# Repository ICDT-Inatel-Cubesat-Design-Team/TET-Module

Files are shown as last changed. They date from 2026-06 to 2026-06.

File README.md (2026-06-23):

<div align="center">
  ICDT Logo
</div>
<h1 align="center">TET Module</h1>

<p align="center">
    
    
    
    
    
</p>

<p align="center">
    <a href="#overview">Overview</a> •
    <a href="#repository-organization">Repository Organization</a> •
    <a href="#releases">Releases</a> •
    <a href="#references">References</a> •
    <a href="#license">License</a>
</p>

## Overview
This project involves the development of the **TET (Telemetry, Encoding & Transmission)** module tailored for a 1U CubeSat platform. The system is engineered to handle TT&C (Tracking, Telemetry, and Command) capabilities, providing long-range telemetry and low-power wireless communication based on the Semtech LR1121 RF transceiver architecture and an STM32L431 microcontroller.

<p align="center">
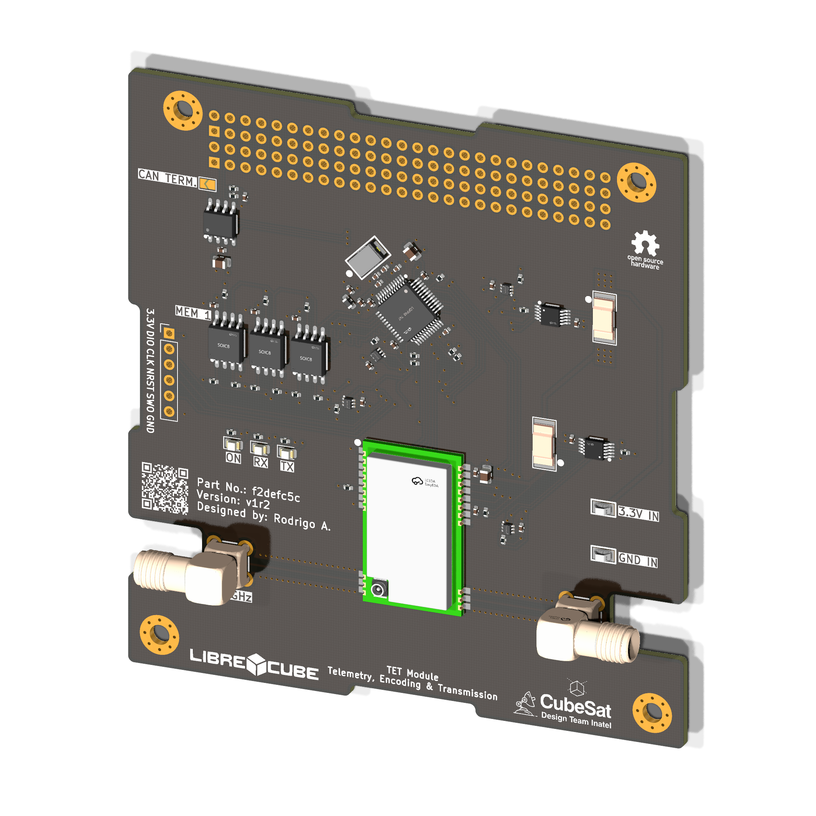
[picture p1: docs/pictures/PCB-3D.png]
    
</p>

**Technical Parameters**
- **RF Architecture:** E80-900M2213S (LR1121)
- **Supported Bands:** Dual-band operation (915 MHz and 2.4 GHz)
- **Modulation Schemes:** LoRa, GFSK, FLRC, and LR-FHSS.
- **RF Interfaces:** Dedicated SMA/IPEX outputs for external antennas
- **External Interfaces:** SPI, GPIO, and CAN bus (via TCAN3414).
- **Power Input:** 3 independent 5 V input channels from the EPS (via PC/104)
- **Power Regulation:** Independent, regulated low-noise 3.3 V rail.
- **Onboard Sensors:** INA226 (current and voltage monitoring) and TMP112 (temperature monitoring and thermal alerts via I2C).
- **Storage:** 3 external SPI flash memories configured with TMR (Triple Modular Redundancy) for telemetry buffering and data storage.

## Repository Organization

* `docs`: Technical documentation and datasheets.
* `hardware`: Core hardware files.
    * `3D`: 3D models (.step).
    * `Fabrication`: BOM and Gerber files for JLCPCB manufacturing.
    * `PCB`: KiCad schematics and layout design.
* `firmware`: Examples of firmware implementation.

## Releases

<table>
  <thead>
    <tr>
      <th>Render</th>
      <th>Board Name</th>
      <th>Status</th>
      <th>Latest Release</th>
      <th>Date</th>
      <th>Datasheet</th>
      <th>BOM</th>
      <th>Ordering Info</th>
    </tr>
  </thead>
  <tbody>
    <tr>
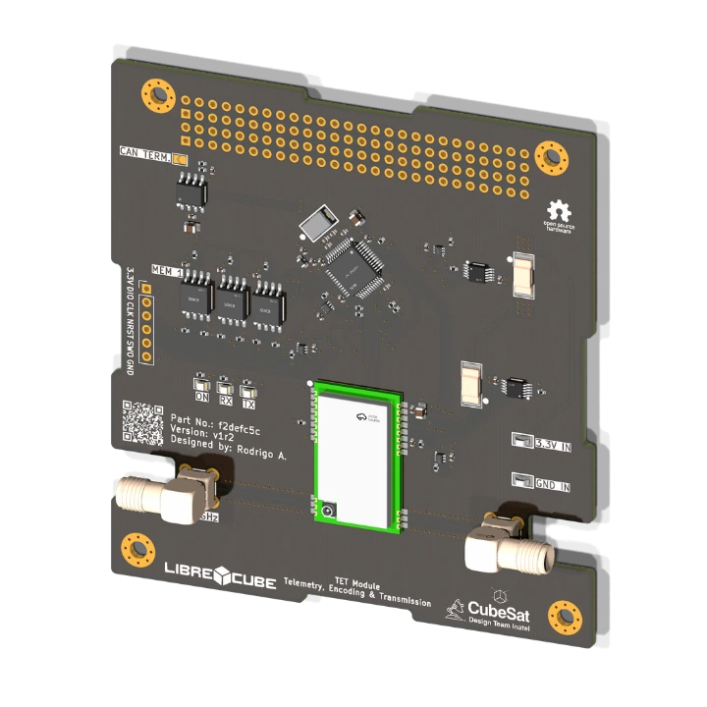
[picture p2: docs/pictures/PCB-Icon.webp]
render
      <td></td>
      <td>TET Module v1</td>
      <td>🧪 Testing</td>
      <td><a href="https://github.com/ICDT-Inatel-Cubesat-Design-Team/TET-Module/releases/tag/v1r2">v1r2</a></td>
      <td>09-06-2026</td>
      <td></td>
      <td>Yes</td>
      <td><a href="hardware/Fabrication/GERBER-TET.zip">GERBER</a> (JLCPCB)</td>
    </tr>
  </tbody>
</table>

## References

This project was inspired by the [TTC](https://github.com/spacelab-ufsc/ttc) and [TTC2](https://github.com/spacelab-ufsc/ttc2) modules from [SpaceLab](https://github.com/spacelab-ufsc/spacelab) UFSC, and the [Build a CubeSat](https://buildacubesat.space/) project. Thank you to both for making your work open-source, and a special thanks to the Build a CubeSat community for their support.

**Missions Associated with this Project**

<p>
  
  
  
<p>

## License

This project is licensed under the permissive, weakly-reciprocal **[CERN-OHL-W-2.0](LICENSE)** open-hardware license. You are free to modify and distribute these files, provided downstream hardware design modifications remain under the same terms.

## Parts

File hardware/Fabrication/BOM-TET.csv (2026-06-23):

Comment | Designator | Footprint | LCSC | Quantity
100 | R5 | R_0402_1005Metric | C25076 | 1
100nF | C1,C14,C19,C2,C20,C22,C23,C24,C25,C26,C27,C30,C31,C32,C33,C40,C5 | C_0402_1005Metric | C307331 | 17
10k | R1,R26,R27,R28,R30,R31,R34,R35,R36,R37,R38,R39,R40,R45 | R_0402_1005Metric | C25744 | 14
10nF | C35 | C_0402_1005Metric | C15195 | 1
10uF | C29,C34 | C_0805_2012Metric | C440198 | 2
120R | FB2 | L_0603_1608Metric | C14709 | 1
1uF | C36,C37 | C_0402_1005Metric | C52923 | 2
200 | R2 | R_0402_1005Metric | C25087 | 1
20pF | C38,C39 | C_0402_1005Metric | C1554 | 2
22uF | C21 | C_0805_2012Metric | C45783 | 1
270 | R10 | R_0402_1005Metric | C2909342 | 1
2m | R32,R7 | RES-SMD_L6.3-W3.1-1 | C695817 | 2
4.7 nF | C8 | C_0402_1005Metric | C1538 | 1
4.7k | R29,R33,R41,R42,R43,R44,R6,R8 | R_0402_1005Metric | C25900 | 8
5015 | U1,U2 | TEST-SMD_L2.7-W1.0 | C2906768 | 2
60.4 | R3,R4 | R_0402_1005Metric | C137954 | 2
8 MHz | U8 | CRYSTAL-SMD_L5.0-W3.2 | C115962 | 1
E80-900M2213S | U14 | WIFIM-SMD_22P-L26.0-W16.0-P1.27-TL | C42464134 | 1
INA226AIDGSR | U21,U3 | MSOP-10_L3.0-W3.0-P0.50-LS5.0-BL | C49851 | 2
ON_LED | D6 | LED_0805_2012Metric | C84256 | 1
RX_LED | D5 | LED_0805_2012Metric | C2297 | 1
SMA | U11,U15 | SMA-TH_SMA-KWE_C7498154 | C7498154 | 2
STM32L431CCT6 | U20 | LQFP-48_L7.0-W7.0-P0.50-LS9.0-BL | C486681 | 1
TCAN3414DR | U5 | SOIC-8_L4.9-W3.9-P1.27-LS6.0-BL | C22396693 | 1
TMP112AIDRLR | U17,U19,U4,U6 | SOT-563_L1.6-W1.2-P0.50-LS1.6-BR | C28927 | 4
TX_LED | D4 | LED_0805_2012Metric | C2296 | 1
W25Q128JVSIQTR | U12,U13,U16 | SOIC-8_L5.3-W5.3-P1.27-LS8.0-BL | C97521 | 3

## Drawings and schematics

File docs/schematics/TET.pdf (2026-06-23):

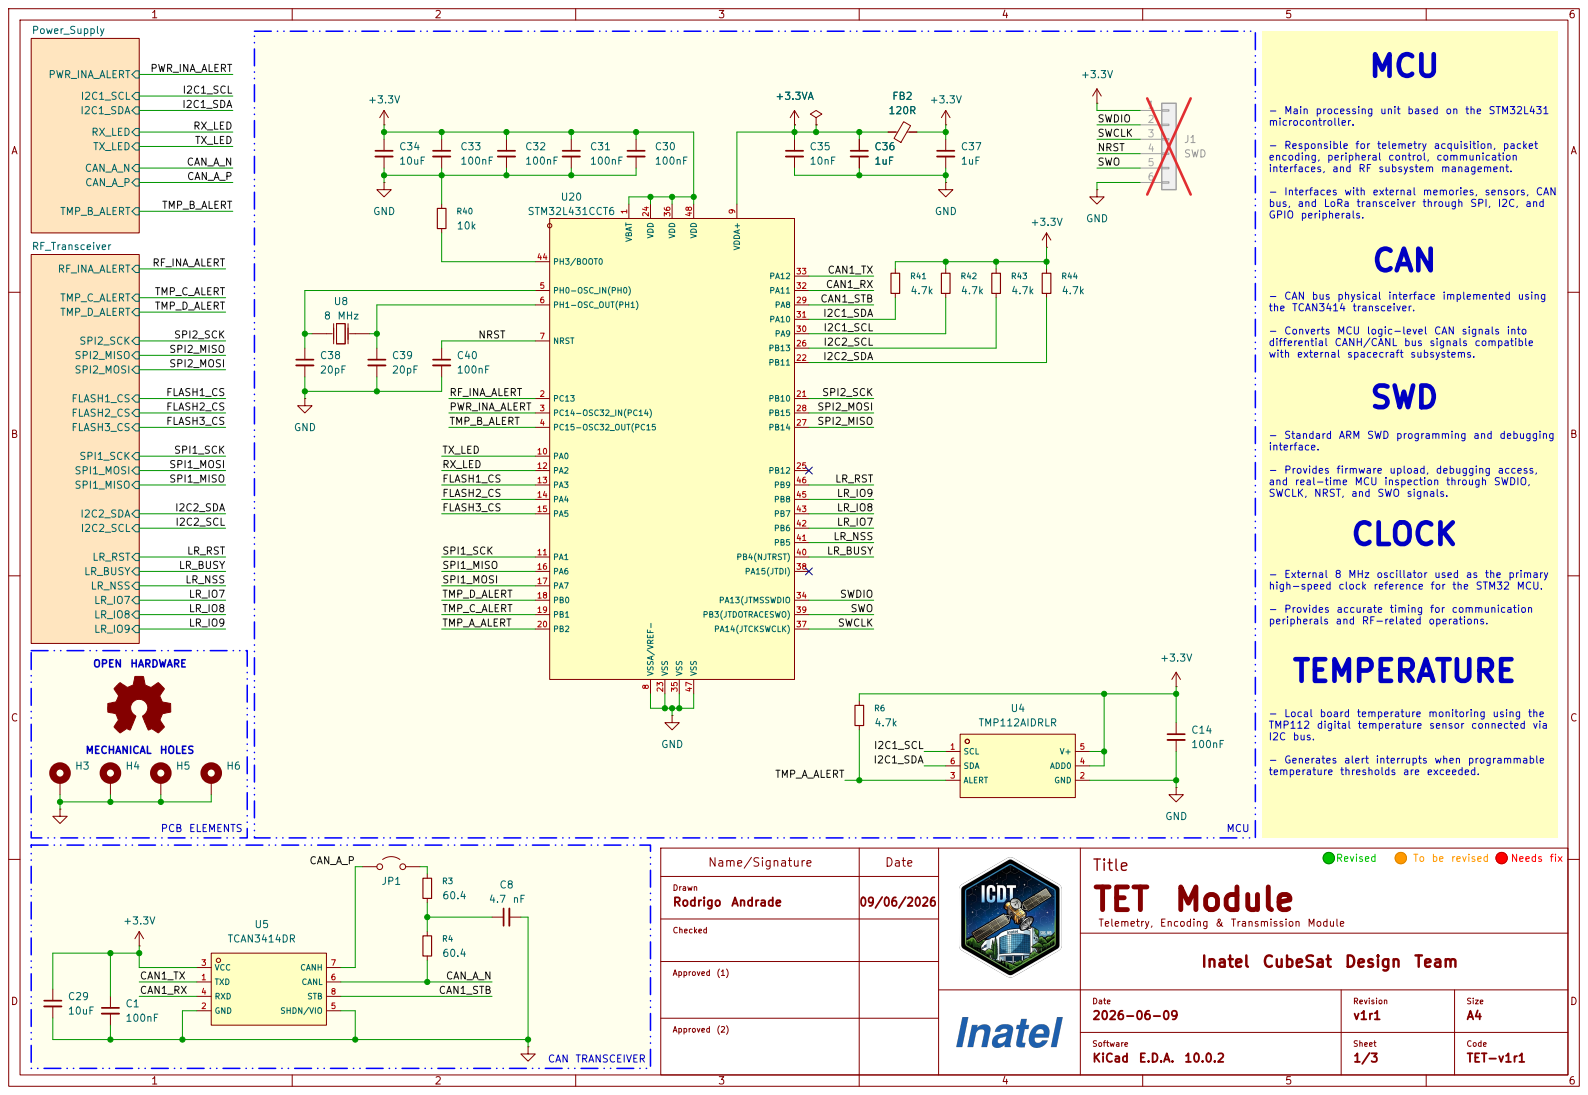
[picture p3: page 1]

- Main processing unit based on the STM32L431 microcontroller. - Responsible for telemetry acquisition, packet

encoding, peripheral control, communication
interfaces, and RF subsystem management. - Interfaces with external memories, sensors, CAN

bus, and LoRa transceiver through SPI, I2C, and GPIO peripherals. - CAN bus physical interface implemented using

9 PA0 10 PA1 11 PA2 12 PA3 13 PA4 14 PA5 15 PA6 16 PA7 17 PB0 18 PB1 19 PB2 20 PB10 21 PB11 22 VSS 23 VDD 24 PB12 25 PB13 26 PB14 27 PB15 28 PA8 29 PA9 30 PA10 31 PA11 32 PA12 33 PA13(JTMSSWDIO 34 VSS 35 VDD 36

the TCAN3414 transceiver. - Converts MCU logic-level CAN signals into

differential CANH/CANL bus signals compatible with external spacecraft subsystems. - Standard ARM SWD programming and debugging
SWD

interface. - Provides firmware upload, debugging access, and real-time MCU inspection through SWDIO,

SWCLK, NRST, and SWO signals. - External 8 MHz oscillator used as the primary

Telemetry, Encoding & Transmission ModuleRevised CLOCK

high-speed clock reference for the STM32 MCU. - Provides accurate timing for communication

peripherals and RF-related operations. - Local board temperature monitoring using the

TMP112 digital temperature sensor connected via
I2C bus. - Generates alert interrupts when programmable

Name/Signature | Date | TET Module | D Title

Drawn Checked Rodrigo Andrade | 09/06/2026

Inatel CubeSat Design Team

2026-06-09 | Revision Software Sheet Date v1r1 | Size KiCad E.D.A. 10.0.2 A4

Code TET-v1r1

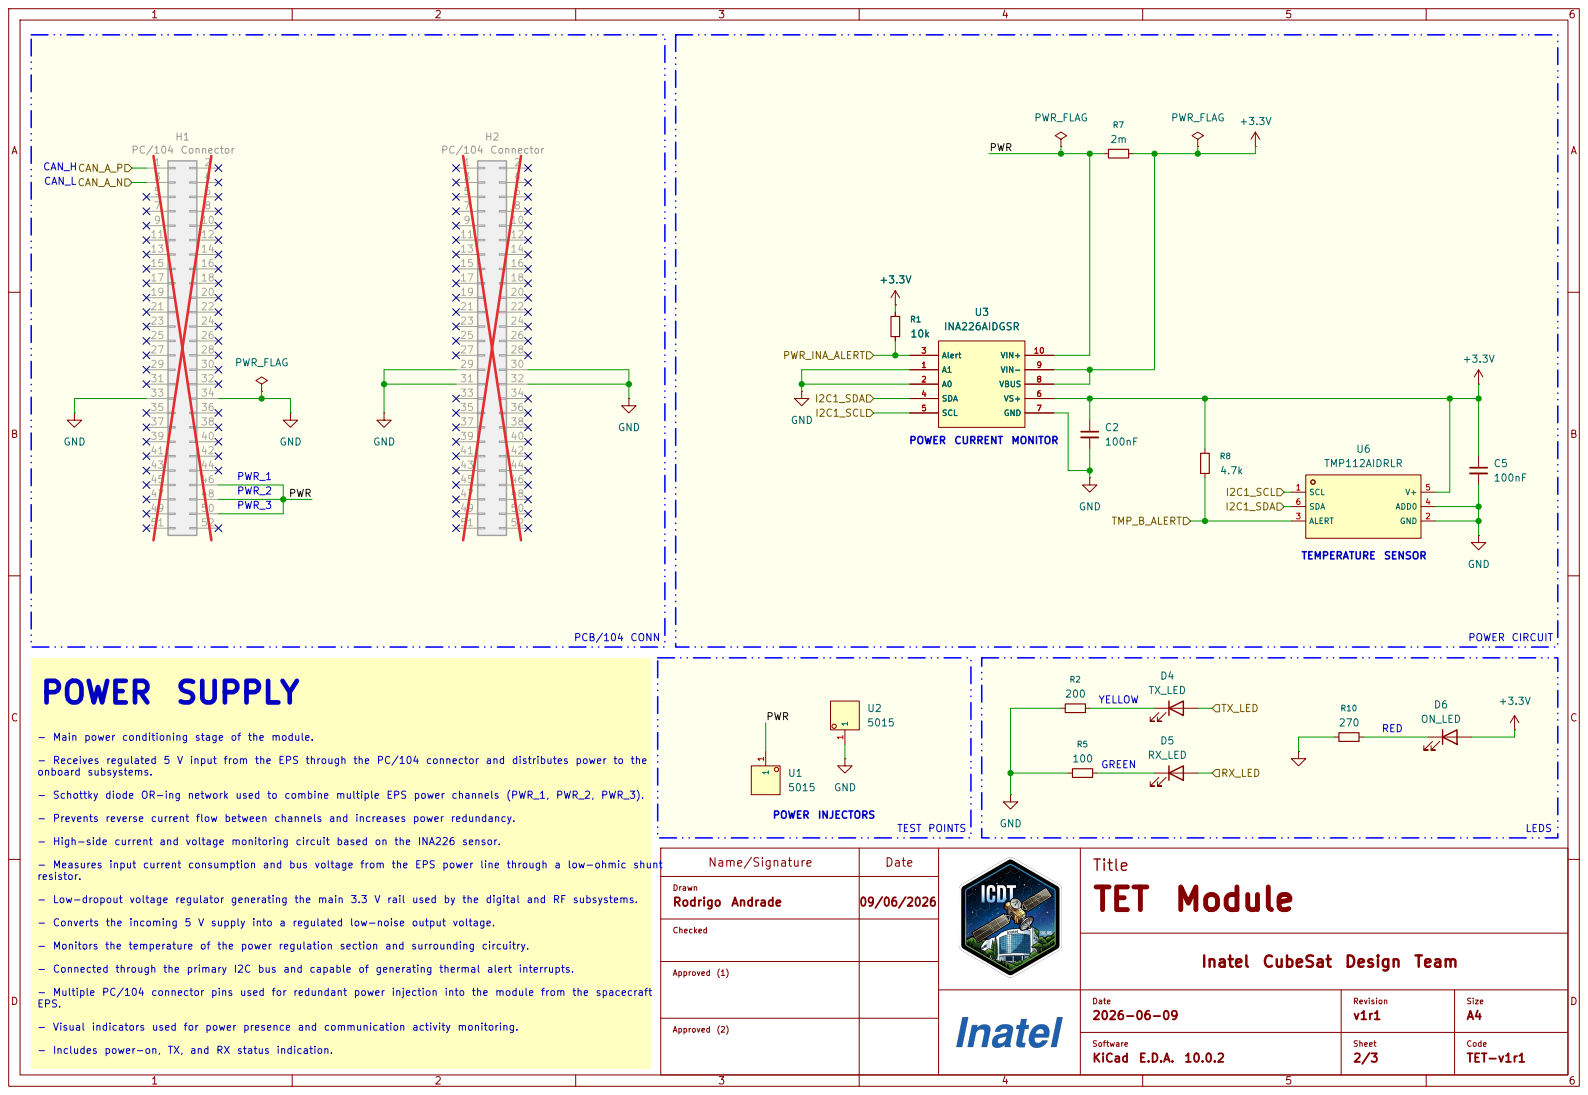
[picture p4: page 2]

Name/Signature | Date | TET Module | D Title

Drawn Checked Rodrigo Andrade | 09/06/2026

Inatel CubeSat Design Team

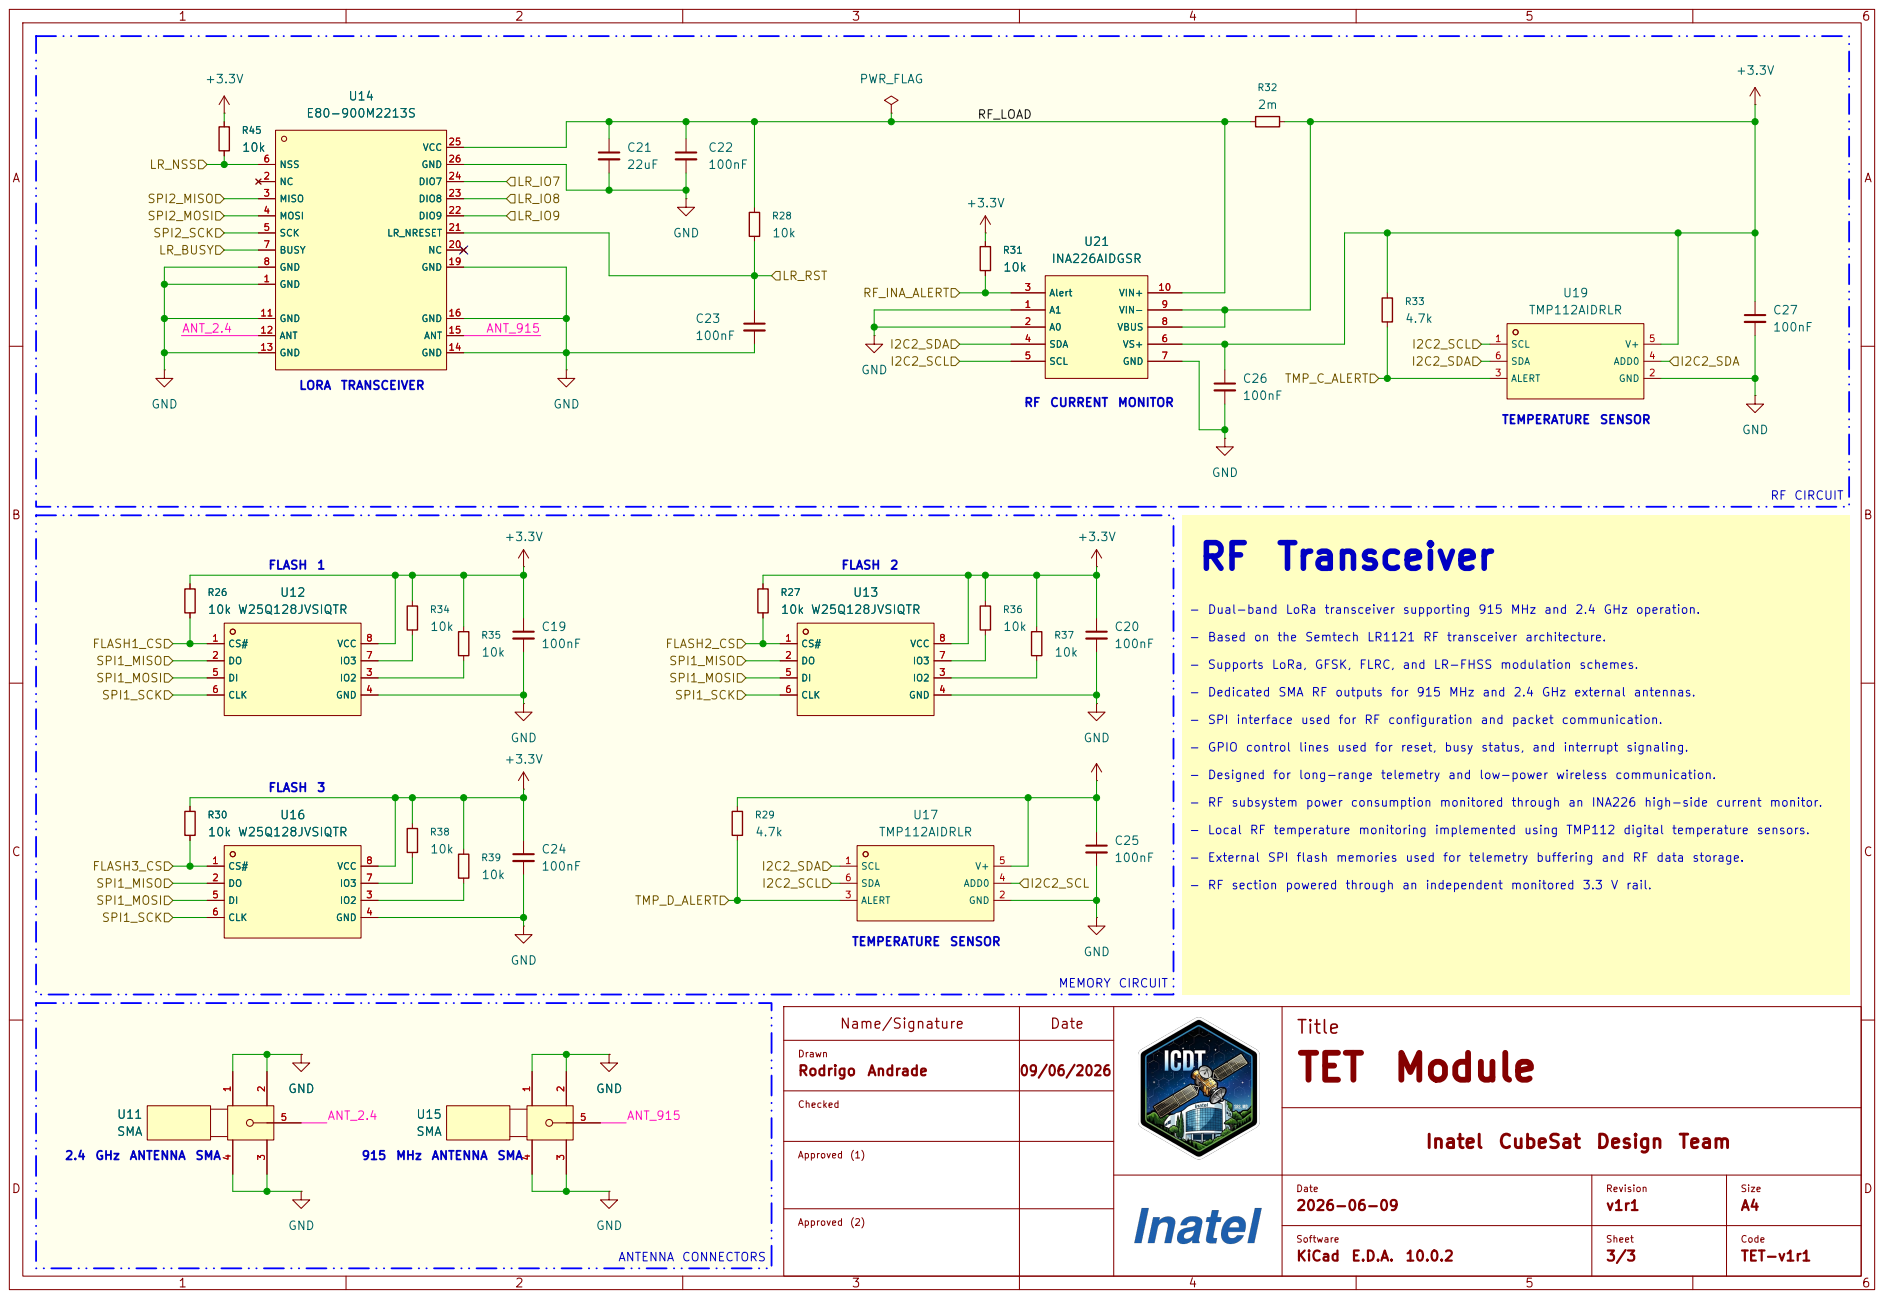
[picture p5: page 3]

Name/Signature | Date | TET Module | D Title

Drawn Checked Rodrigo Andrade | 09/06/2026

Inatel CubeSat Design Team

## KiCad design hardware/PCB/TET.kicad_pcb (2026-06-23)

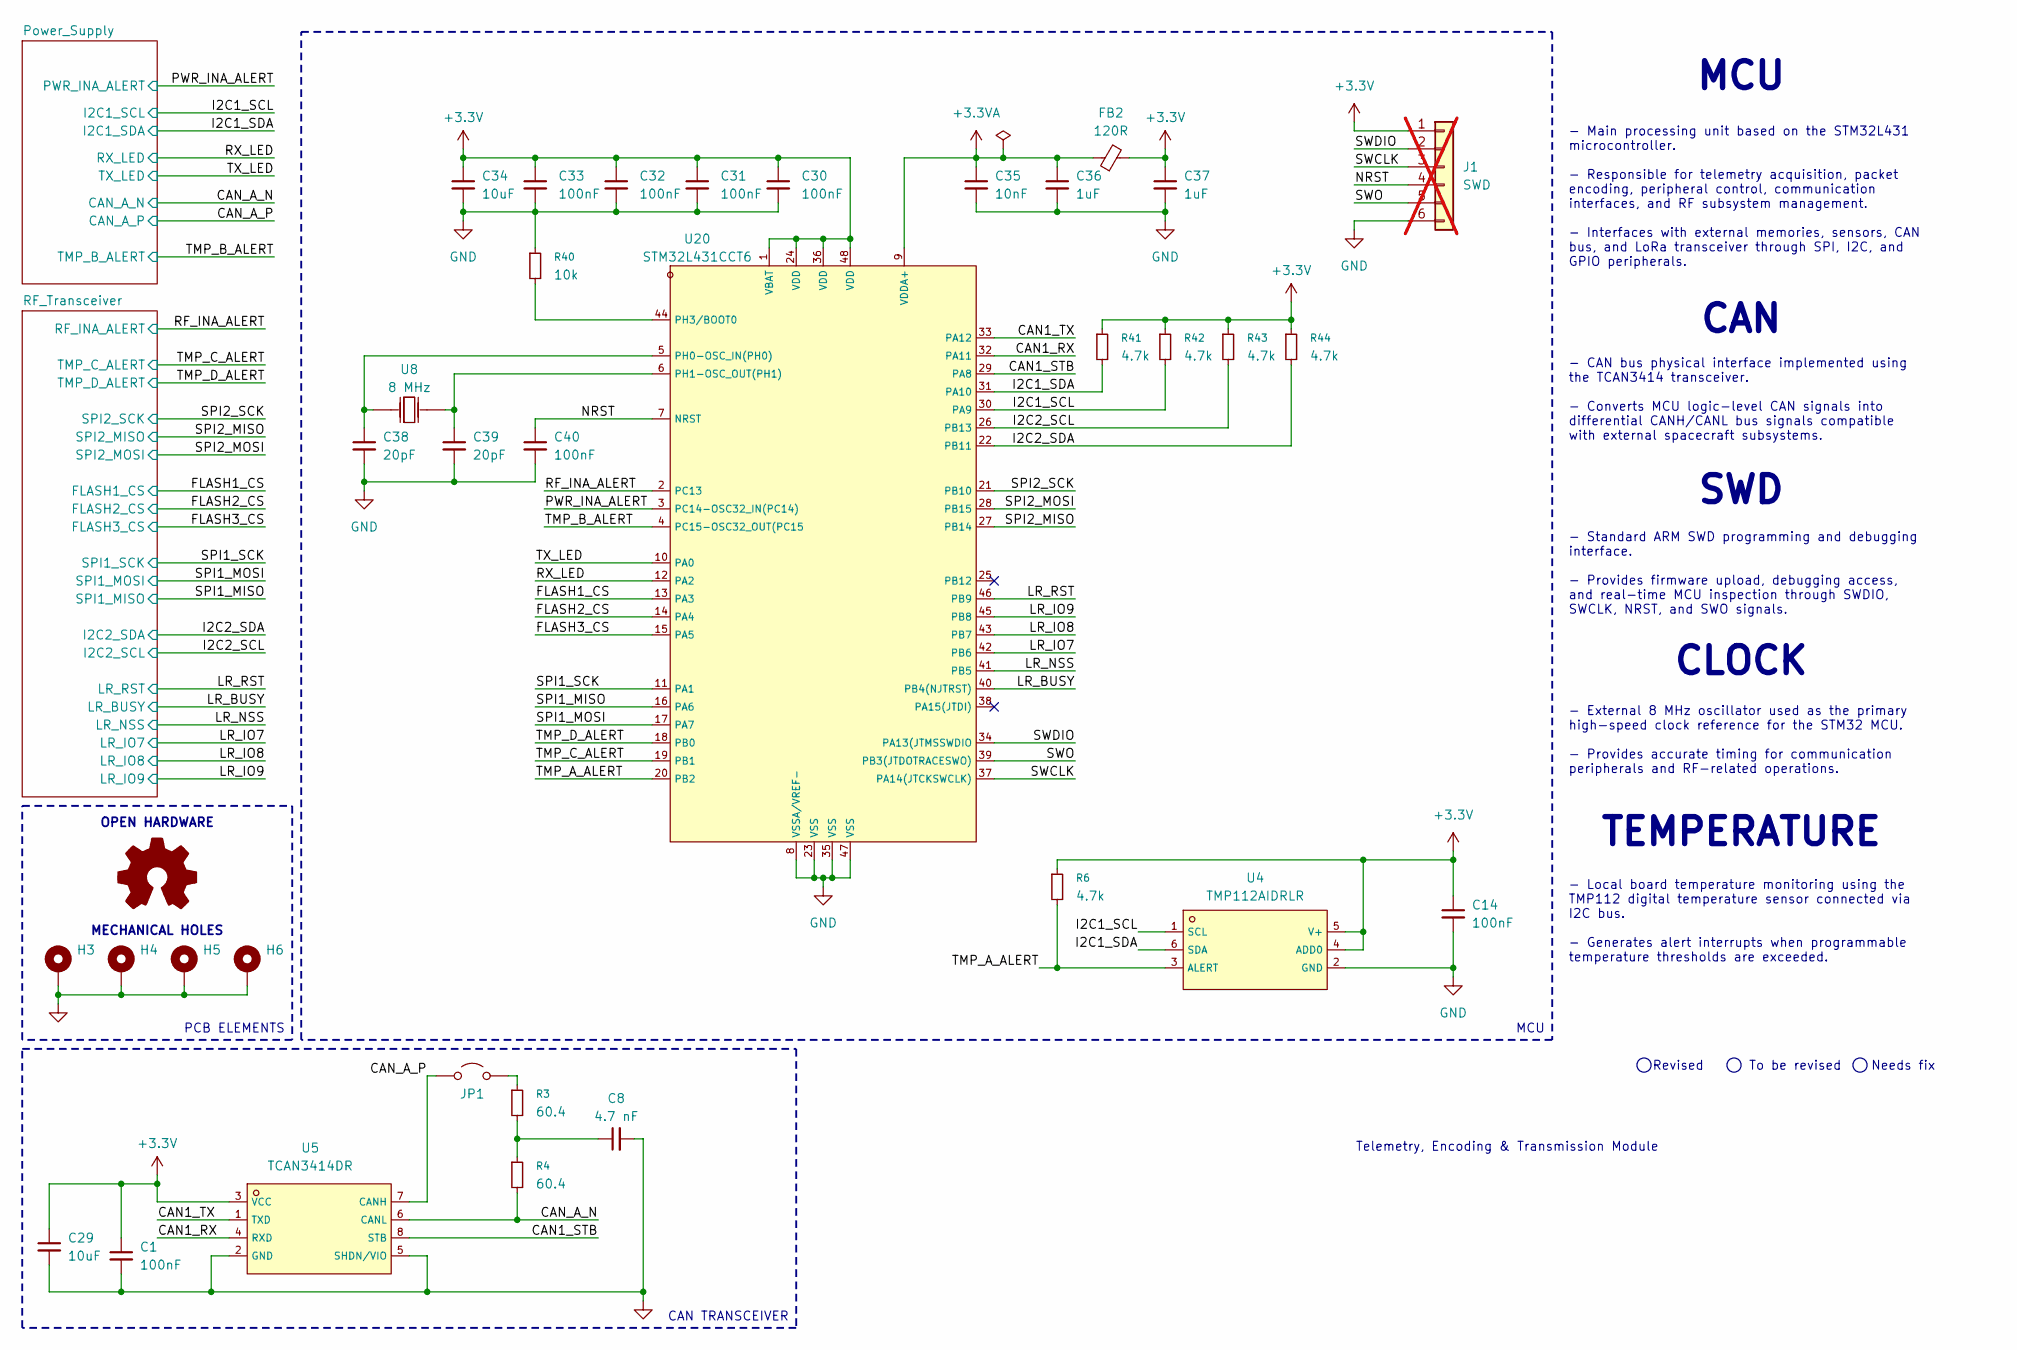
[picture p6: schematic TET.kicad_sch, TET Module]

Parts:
C1, C14, C30, C31, C32, C33, C40: 100nF; C_0402_1005Metric
C8: 4.7 nF; C_0402_1005Metric
C29, C34: 10uF; C_0805_2012Metric
C35: 10nF; C_0402_1005Metric
C36, C37: 1uF; C_0402_1005Metric
C38, C39: 20pF; C_0402_1005Metric
FB2: 120R; L_0603_1608Metric; LCSC C14709
H3, H4, H5, H6: MountingHole_Pad; MountingHole_3.2mm_M3_Pad_Via
J1: SWD; PinHeader_1x06_P2.54mm_Vertical; not fitted
JP1: Jumper_2_Open; SolderJumper-2_P1.3mm_Open_TrianglePad1.0x1.5mm
R3, R4: 60.4; R_0402_1005Metric
R6, R41, R42, R43, R44: 4.7k; R_0402_1005Metric
R40: 10k; R_0402_1005Metric
REF1: Logo_Open_Hardware_Small; OSHW-Logo_5.7x6mm_SilkScreen
U4: TMP112AIDRLR; SOT-563_L1.6-W1.2-P0.50-LS1.6-BR; LCSC C28927
U5: TCAN3414DR; SOIC-8_L4.9-W3.9-P1.27-LS6.0-BL; LCSC C22396693
U8: 8 MHz; CRYSTAL-SMD_L5.0-W3.2; LCSC C115962
U20: STM32L431CCT6; LQFP-48_L7.0-W7.0-P0.50-LS9.0-BL; LCSC C486681

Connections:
+3.3V: C1.1, C14.1, C29.1, C30.1, C31.1, C32.1, C33.1, C34.1, C37.1, FB2.2, J1.1, R6.1, R41.1, R42.1, R43.1, R44.1, U4.4 (ADD0), U4.5 (V+), U5.3 (VCC), U20.1 (VBAT), U20.24 (VDD), U20.36 (VDD), U20.48 (VDD); also elsewhere on the board
+3.3VA: C35.1, C36.1, FB2.1, U20.9 (VDDA+)
/CAN1_RX: U5.4 (RXD), U20.32 (PA11)
/CAN1_STB: U5.8 (STB), U20.29 (PA8)
/CAN1_TX: U5.1 (TXD), U20.33 (PA12)
/CAN_A_N: R4.2, U5.6 (CANL); also elsewhere on the board
/CAN_A_P: JP1.1 (A), U5.7 (CANH); also elsewhere on the board
/FLASH1_CS: U20.13 (PA3); also elsewhere on the board
/FLASH2_CS: U20.14 (PA4); also elsewhere on the board
/FLASH3_CS: U20.15 (PA5); also elsewhere on the board
/I2C1_SCL: R42.2, U4.1 (SCL), U20.30 (PA9); also elsewhere on the board
/I2C1_SDA: R41.2, U4.6 (SDA), U20.31 (PA10); also elsewhere on the board
/I2C2_SCL: R43.2, U20.26 (PB13); also elsewhere on the board
/I2C2_SDA: R44.2, U20.22 (PB11); also elsewhere on the board
/LR_BUSY: U20.40 (PB4(NJTRST)); also elsewhere on the board
/LR_IO7: U20.42 (PB6); also elsewhere on the board
/LR_IO8: U20.43 (PB7); also elsewhere on the board
/LR_IO9: U20.45 (PB8); also elsewhere on the board
/LR_NSS: U20.41 (PB5); also elsewhere on the board
/LR_RST: U20.46 (PB9); also elsewhere on the board
/NRST: C40.1, J1.4, U20.7 (NRST)
/PWR_INA_ALERT: U20.3 (PC14-OSC32_IN(PC14)); also elsewhere on the board
/RF_INA_ALERT: U20.2 (PC13); also elsewhere on the board
/RX_LED: U20.12 (PA2); also elsewhere on the board
/SPI1_MISO: U20.16 (PA6); also elsewhere on the board
/SPI1_MOSI: U20.17 (PA7); also elsewhere on the board
/SPI1_SCK: U20.11 (PA1); also elsewhere on the board
/SPI2_MISO: U20.27 (PB14); also elsewhere on the board
/SPI2_MOSI: U20.28 (PB15); also elsewhere on the board
/SPI2_SCK: U20.21 (PB10); also elsewhere on the board
/SWCLK: J1.3, U20.37 (PA14(JTCKSWCLK))
/SWDIO: J1.2, U20.34 (PA13(JTMSSWDIO)
/SWO: J1.5, U20.39 (PB3(JTDOTRACESWO))
/TMP_A_ALERT: R6.2, U4.3 (ALERT), U20.20 (PB2)
/TMP_B_ALERT: U20.4 (PC15-OSC32_OUT(PC15); also elsewhere on the board
/TMP_C_ALERT: U20.19 (PB1); also elsewhere on the board
/TMP_D_ALERT: U20.18 (PB0); also elsewhere on the board
/TX_LED: U20.10 (PA0); also elsewhere on the board
GND: C1.2, C8.2, C14.2, C29.2, C30.2, C31.2, C32.2, C33.2, C34.2, C35.2, C36.2, C37.2, C38.2, C39.2, C40.2, H3.1 (1_1), H4.1 (1_1), H5.1 (1_1), H6.1 (1_1), J1.6, R40.1, U4.2 (GND), U5.2 (GND), U5.5 (SHDN/VIO), U20.8 (VSSA/VREF-), U20.23 (VSS), U20.35 (VSS), U20.47 (VSS); also elsewhere on the board
unnamed: C8.1, R3.2, R4.1
unnamed: JP1.2 (B), R3.1
unnamed: C38.1, U8.2 (OSC2), U20.5 (PH0-OSC_IN(PH0))
unnamed: C39.1, U8.1 (OSC1), U20.6 (PH1-OSC_OUT(PH1))
unnamed: R40.2, U20.44 (PH3/BOOT0)

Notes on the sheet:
SWD
Revised
TEMPERATURE
Needs fix
MCU
OPEN HARDWARE
CLOCK
MECHANICAL HOLES
To be revised
CAN
Telemetry, Encoding & Transmission Module
PCB ELEMENTS
CAN TRANSCEIVER
- Main processing unit based on the STM32L431 microcontroller. - Responsible for telemetry acquisition, packet encoding, peripheral control, communication interfaces, and RF subsystem management. - Interfaces with external memories, sensors, CAN bus, and LoRa transceiver through SPI, I2C, and GPIO 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

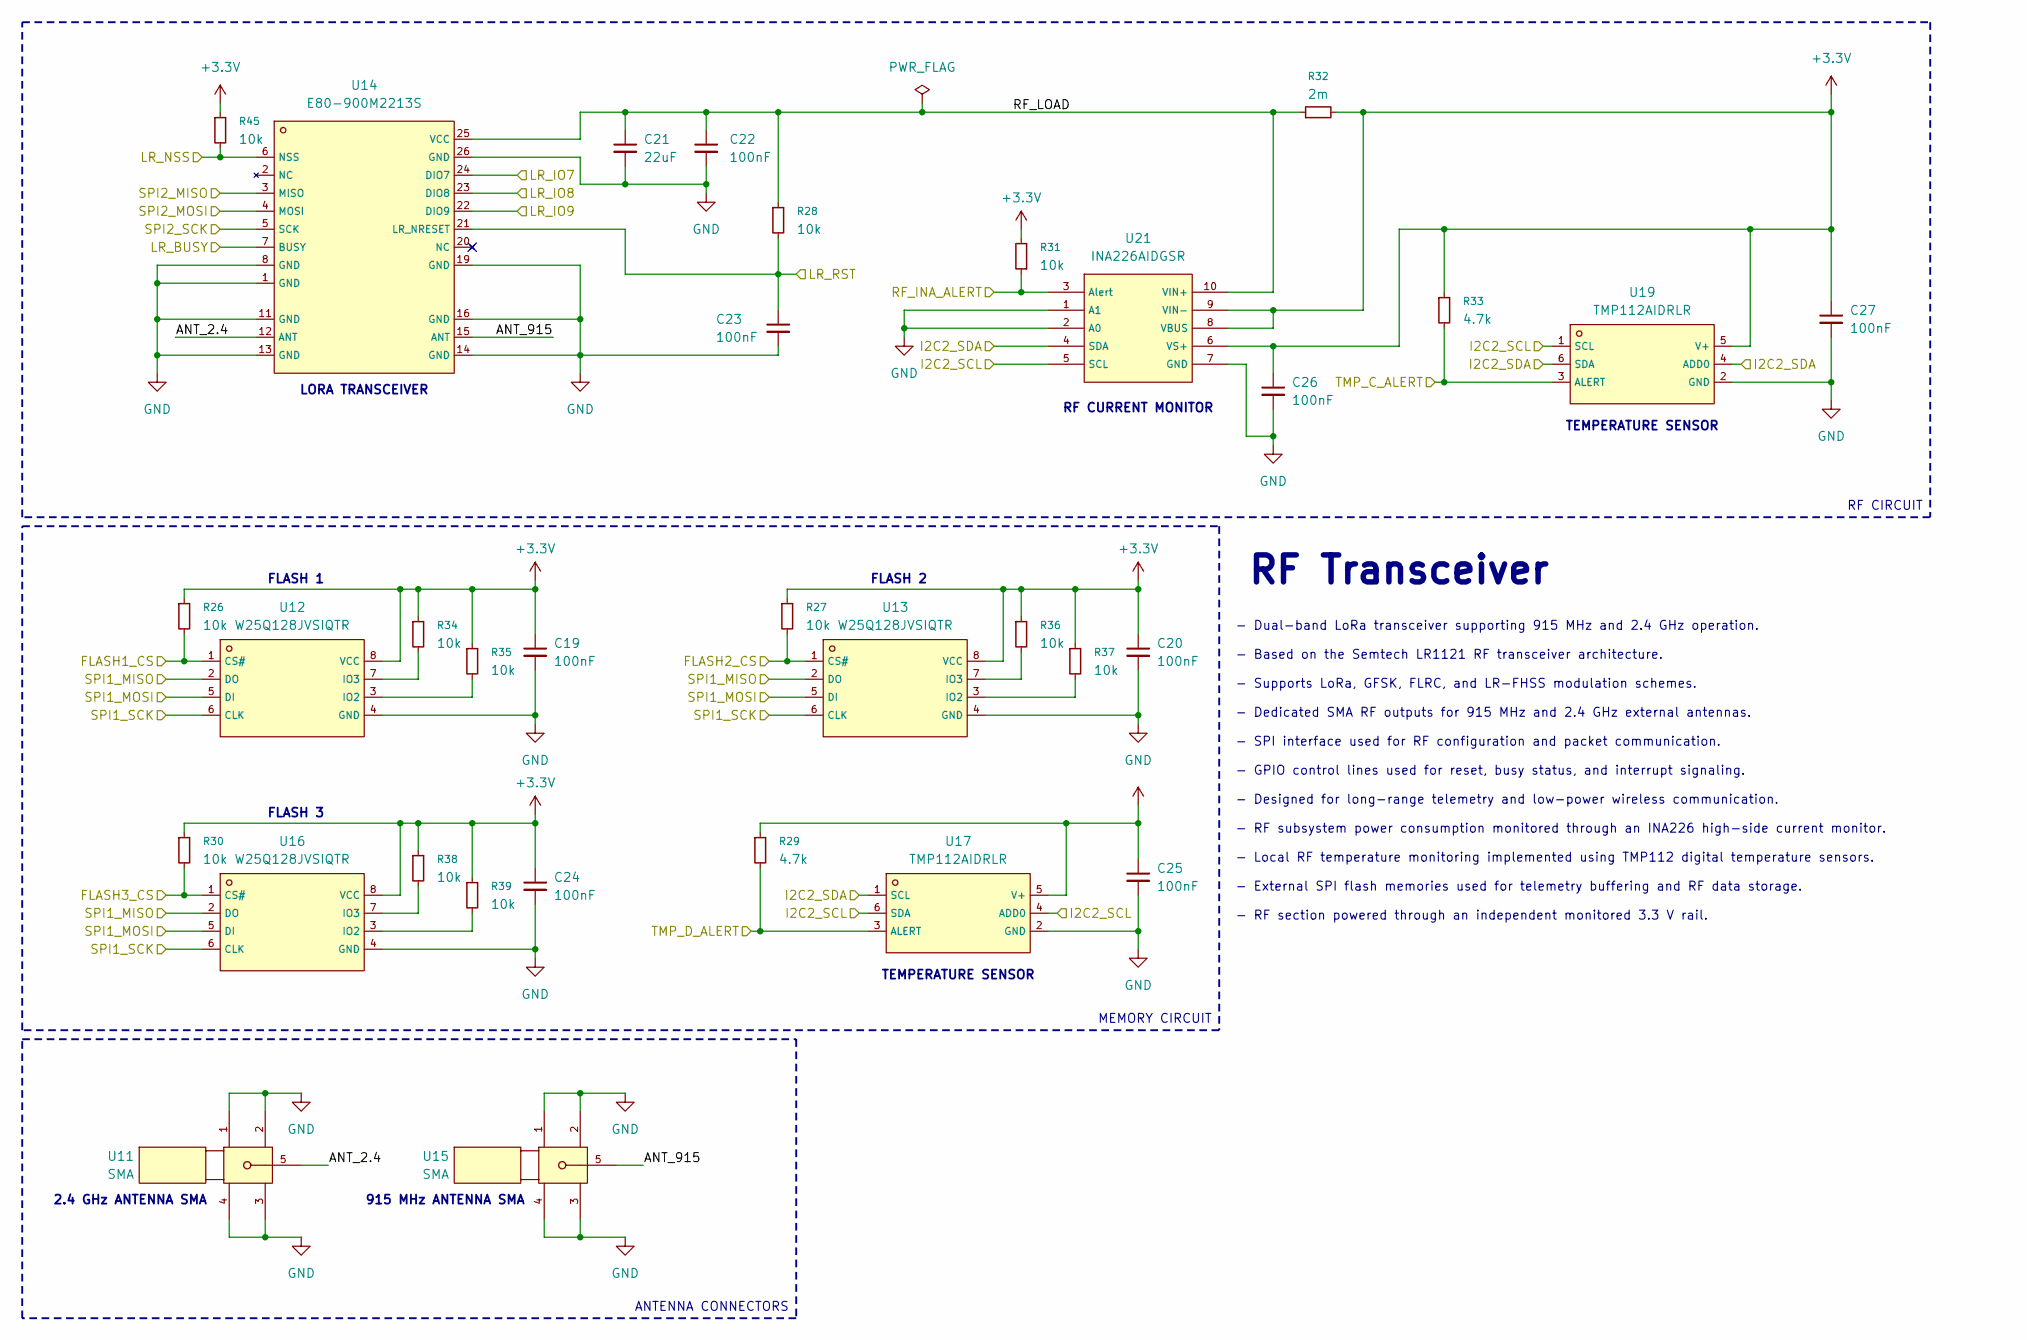
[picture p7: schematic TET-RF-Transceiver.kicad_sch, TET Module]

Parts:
C19, C20, C22, C23, C24, C25, C26, C27: 100nF; C_0402_1005Metric
C21: 22uF; C_0805_2012Metric
R26, R27, R28, R30, R31, R34, R35, R36, R37, R38, R39, R45: 10k; R_0402_1005Metric
R29, R33: 4.7k; R_0402_1005Metric
R32: 2m; RES-SMD_L6.3-W3.1-1; LCSC C695817
U11, U15: SMA; SMA-TH_SMA-KWE_C7498154; LCSC C7498154
U12, U13, U16: W25Q128JVSIQTR; SOIC-8_L5.3-W5.3-P1.27-LS8.0-BL; LCSC C97521
U14: E80-900M2213S; WIFIM-SMD_22P-L26.0-W16.0-P1.27-TL; LCSC C42464134
U17, U19: TMP112AIDRLR; SOT-563_L1.6-W1.2-P0.50-LS1.6-BR; LCSC C28927
U21: INA226AIDGSR; MSOP-10_L3.0-W3.0-P0.50-LS5.0-BL; LCSC C49851

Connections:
+3.3V: C19.1, C20.1, C24.1, C25.1, C26.1, C27.1, R26.1, R27.1, R29.1, R30.1, R31.2, R32.2, R33.1, R34.1, R35.1, R36.1, R37.1, R38.1, R39.1, R45.1, U12.8 (VCC), U13.8 (VCC), U16.8 (VCC), U17.5 (V+), U19.5 (V+), U21.6 (VS+), U21.8 (VBUS), U21.9 (VIN-); also elsewhere on the board
/FLASH1_CS: R26.2, U12.1 (CS#); also elsewhere on the board
/FLASH2_CS: R27.2, U13.1 (CS#); also elsewhere on the board
/FLASH3_CS: R30.2, U16.1 (CS#); also elsewhere on the board
/I2C2_SCL: U17.4 (ADD0), U17.6 (SDA), U19.1 (SCL), U21.5 (SCL); also elsewhere on the board
/I2C2_SDA: U17.1 (SCL), U19.4 (ADD0), U19.6 (SDA), U21.4 (SDA); also elsewhere on the board
/LR_BUSY: U14.7 (BUSY); also elsewhere on the board
/LR_IO7: U14.24 (DIO7); also elsewhere on the board
/LR_IO8: U14.23 (DIO8); also elsewhere on the board
/LR_IO9: U14.22 (DIO9); also elsewhere on the board
/LR_NSS: R45.2, U14.6 (NSS); also elsewhere on the board
/LR_RST: C23.1, R28.2, U14.21 (LR_NRESET); also elsewhere on the board
/RF_INA_ALERT: R31.1, U21.3 (Alert); also elsewhere on the board
/RF_Transceiver/ANT_2.4: U11.5, U14.12 (ANT)
/RF_Transceiver/ANT_915: U14.15 (ANT), U15.5
/RF_Transceiver/RF_LOAD: C21.1, C22.1, R28.1, R32.1, U14.25 (VCC), U21.10 (VIN+)
/SPI1_MISO: U12.2 (DO), U13.2 (DO), U16.2 (DO); also elsewhere on the board
/SPI1_MOSI: U12.5 (DI), U13.5 (DI), U16.5 (DI); also elsewhere on the board
/SPI1_SCK: U12.6 (CLK), U13.6 (CLK), U16.6 (CLK); also elsewhere on the board
/SPI2_MISO: U14.3 (MISO); also elsewhere on the board
/SPI2_MOSI: U14.4 (MOSI); also elsewhere on the board
/SPI2_SCK: U14.5 (SCK); also elsewhere on the board
/TMP_C_ALERT: R33.2, U19.3 (ALERT); also elsewhere on the board
/TMP_D_ALERT: R29.2, U17.3 (ALERT); also elsewhere on the board
GND: C19.2, C20.2, C21.2, C22.2, C23.2, C24.2, C25.2, C26.2, C27.2, U11.1, U11.2, U11.3, U11.4, U12.4 (GND), U13.4 (GND), U14.1 (GND), U14.8 (GND), U14.11 (GND), U14.13 (GND), U14.14 (GND), U14.16 (GND), U14.19 (GND), U14.26 (GND), U15.1, U15.2, U15.3, U15.4, U16.4 (GND), U17.2 (GND), U19.2 (GND), U21.1 (A1), U21.2 (A0), U21.7 (GND); also elsewhere on the board
unnamed: R35.2, U12.3 (IO2)
unnamed: R34.2, U12.7 (IO3)
unnamed: R37.2, U13.3 (IO2)
unnamed: R36.2, U13.7 (IO3)
unnamed: R39.2, U16.3 (IO2)
unnamed: R38.2, U16.7 (IO3)

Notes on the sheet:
TEMPERATURE SENSOR
915 MHz ANTENNA SMA
2.4 GHz ANTENNA SMA
FLASH 1
LORA TRANSCEIVER
RF CURRENT MONITOR
FLASH 3
FLASH 2
RF Transceiver
MEMORY CIRCUIT
- Dual-band LoRa transceiver supporting 915 MHz and 2.4 GHz operation. - Based on the Semtech LR1121 RF transceiver architecture. - Supports LoRa, GFSK, FLRC, and LR-FHSS modulation schemes. - Dedicated SMA RF outputs for 915 MHz and 2.4 GHz external antennas. - SPI interface used for RF configurat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
ANTENNA CONNECTORS
RF CIRCUIT

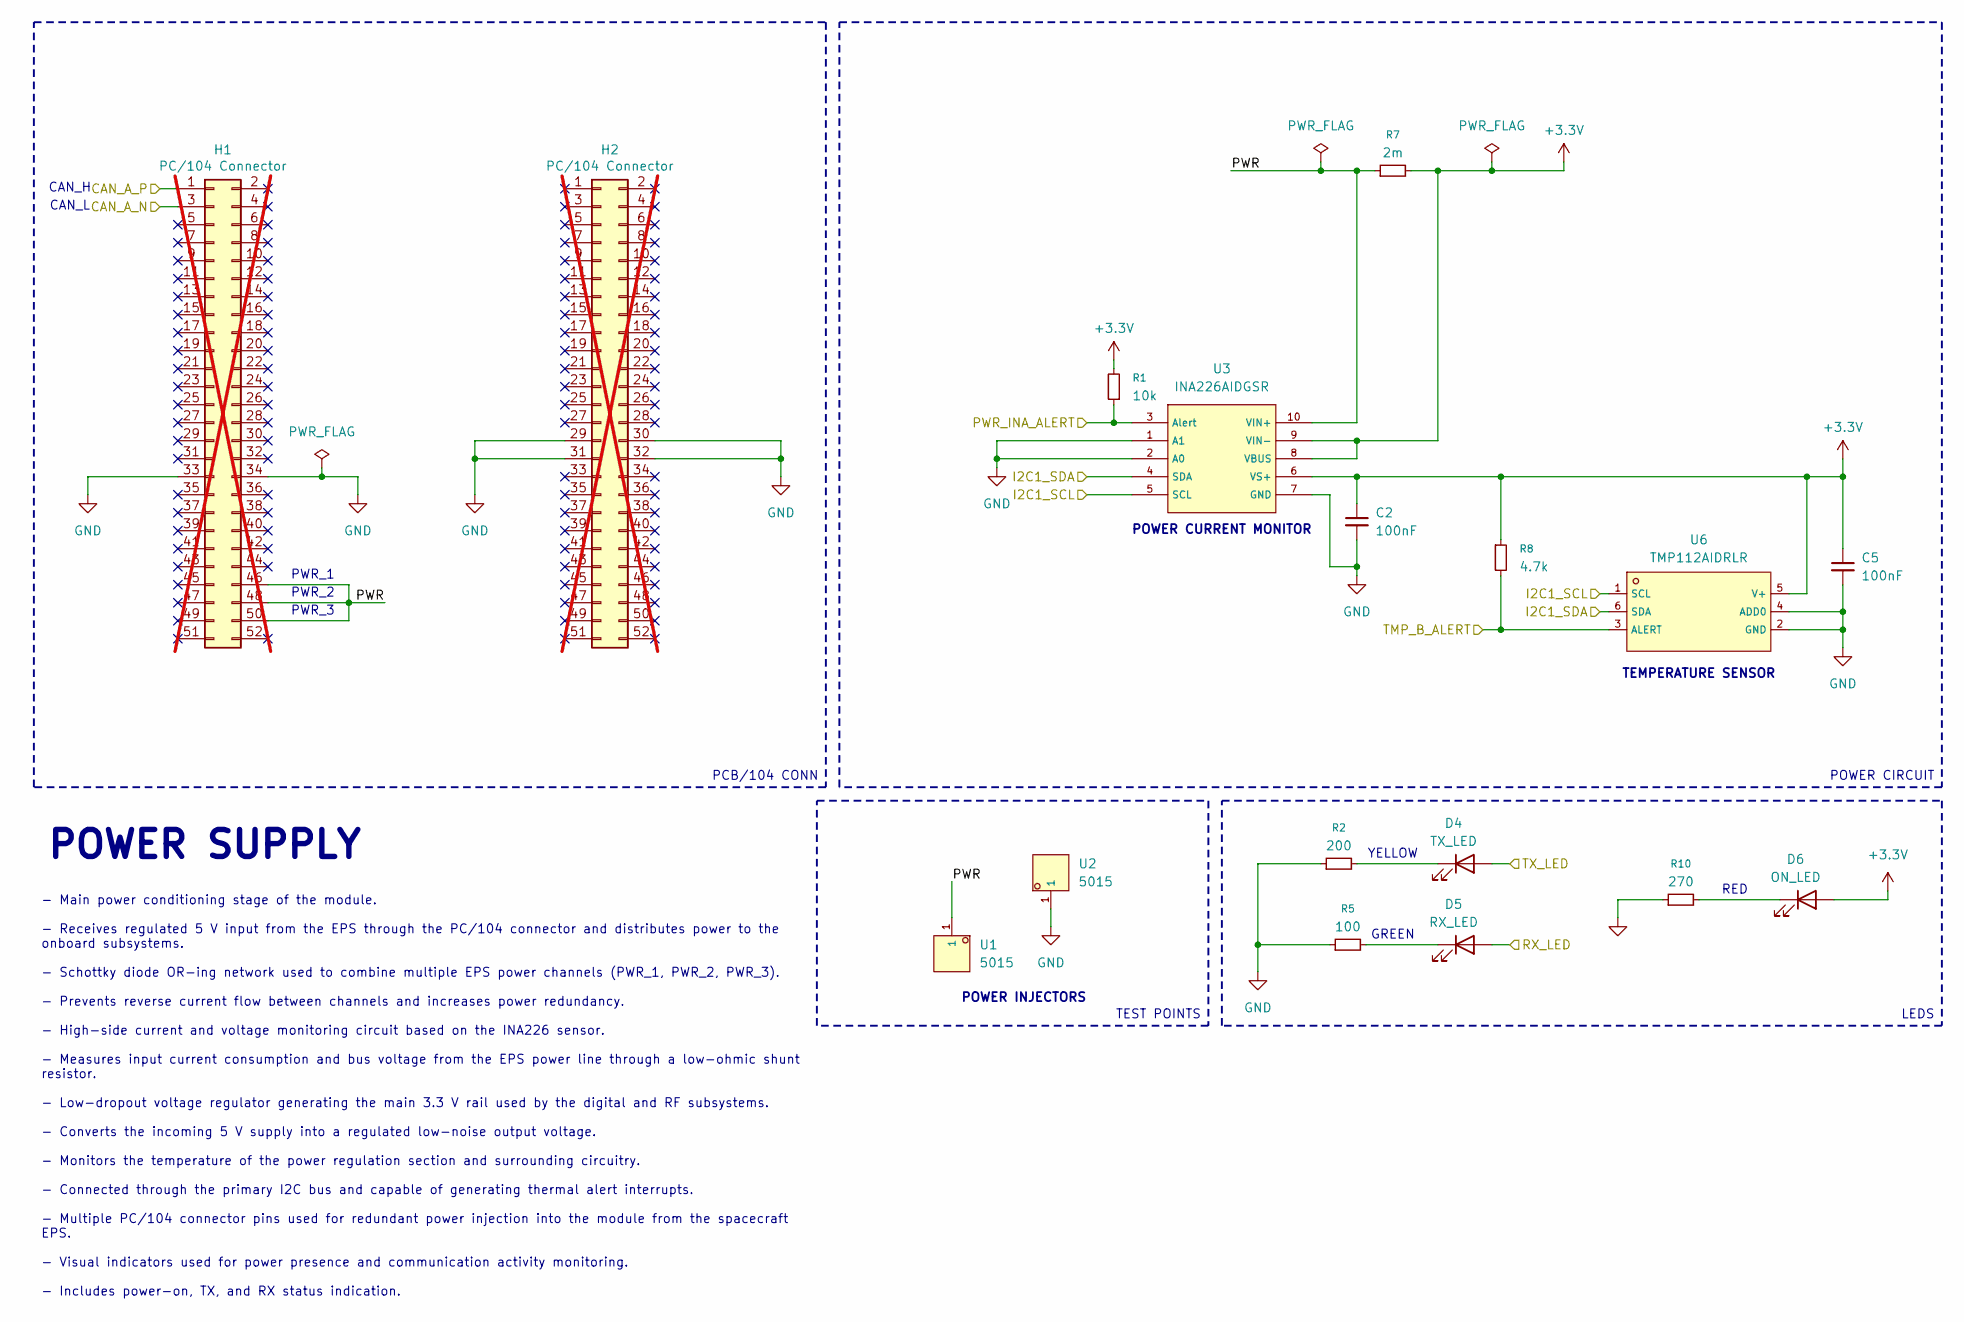
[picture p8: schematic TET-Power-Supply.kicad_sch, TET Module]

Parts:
C2, C5: 100nF; C_0402_1005Metric
D4: TX_LED; LED_0805_2012Metric; LCSC C2296
D5: RX_LED; LED_0805_2012Metric; LCSC C2297
D6: ON_LED; LED_0805_2012Metric; LCSC C84256
H1, H2: PC/104 Connector; PinHeader_2x26_P2.54mm_Vertical; not fitted
R1: 10k; R_0402_1005Metric
R2: 200; R_0402_1005Metric
R5: 100; R_0402_1005Metric
R7: 2m; RES-SMD_L6.3-W3.1-1; LCSC C695817
R8: 4.7k; R_0402_1005Metric
R10: 270; R_0402_1005Metric
U1, U2: 5015; TEST-SMD_L2.7-W1.0; LCSC C2906768
U3: INA226AIDGSR; MSOP-10_L3.0-W3.0-P0.50-LS5.0-BL; LCSC C49851
U6: TMP112AIDRLR; SOT-563_L1.6-W1.2-P0.50-LS1.6-BR; LCSC C28927

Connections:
+3.3V: C2.1, C5.1, D6.2 (A), R1.2, R7.2, R8.1, U3.6 (VS+), U3.8 (VBUS), U3.9 (VIN-), U6.5 (V+); also elsewhere on the board
/CAN_A_N: H1.3; also elsewhere on the board
/CAN_A_P: H1.1; also elsewhere on the board
/I2C1_SCL: U3.5 (SCL), U6.1 (SCL); also elsewhere on the board
/I2C1_SDA: U3.4 (SDA), U6.6 (SDA); also elsewhere on the board
/PWR_INA_ALERT: R1.1, U3.3 (Alert); also elsewhere on the board
/Power_Supply/PWR: H1.46, H1.48, H1.50, R7.1, U1.1 (1_1), U3.10 (VIN+)
/RX_LED: D5.2 (A); also elsewhere on the board
/TMP_B_ALERT: R8.2, U6.3 (ALERT); also elsewhere on the board
/TX_LED: D4.2 (A); also elsewhere on the board
GND: C2.2, C5.2, H1.33, H1.34, H2.29, H2.30, H2.31, H2.32, R2.1, R5.1, R10.1, U2.1 (1_1), U3.1 (A1), U3.2 (A0), U3.7 (GND), U6.2 (GND), U6.4 (ADD0); also elsewhere on the board
unnamed: D4.1 (K), R2.2
unnamed: D5.1 (K), R5.2
unnamed: D6.1 (K), R10.2

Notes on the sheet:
POWER INJECTORS
CAN_L
POWER SUPPLY
TEMPERATURE SENSOR
POWER CURRENT MONITOR
CAN_H
RED
PWR_2
YELLOW
PWR_1
PWR_3
GREEN
TEST POINTS
PCB/104 CONN
- Main power conditioning stage of the module. - Receives regulated 5 V input from the EPS through the PC/104 connector and distributes power to the onboard subsystems. - Schottky diode OR-ing network used to combine multiple EPS power channels (PWR_1, PWR_2, PWR_3). - Prevents reverse current flow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
POWER CIRCUIT
LEDS

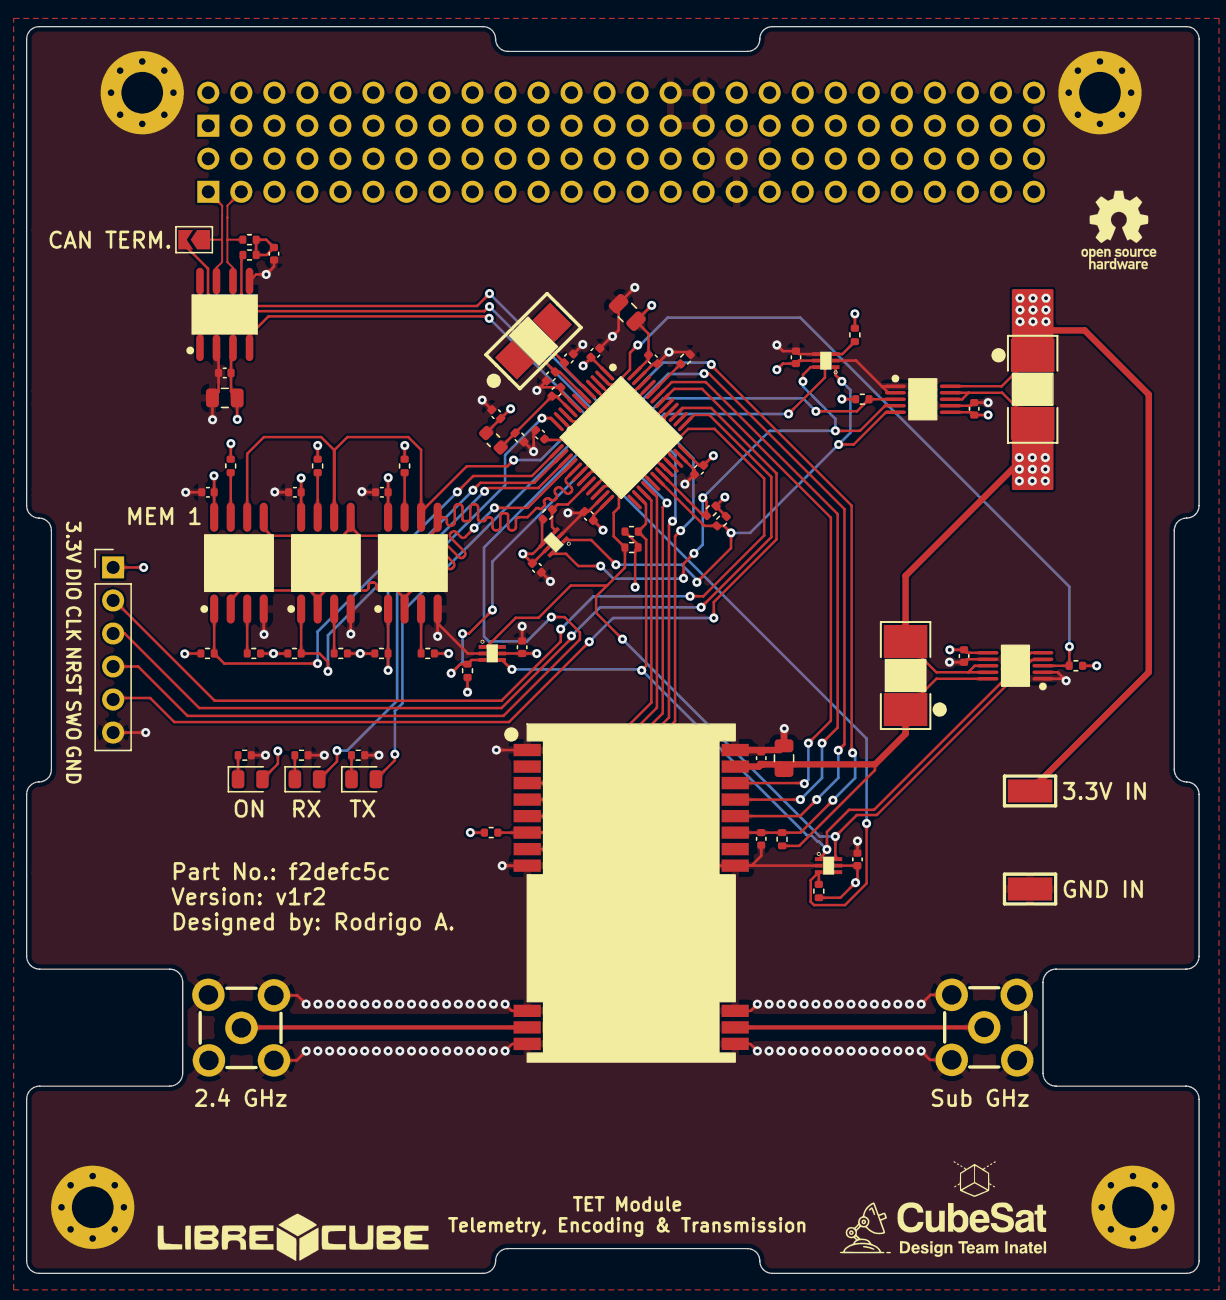
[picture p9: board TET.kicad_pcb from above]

Board: 4 copper layers, 90.2 x 95.9 mm, 85 parts (0 on the bottom side), 57 nets.

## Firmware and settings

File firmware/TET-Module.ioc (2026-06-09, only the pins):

Mcu.UserName=STM32L431CCTx
PA0.GPIO_Label=TX_LED
PA0.Signal=GPIO_Output
PA1.Signal=SPI1_SCK
PA10.Signal=I2C1_SDA
PA11.Signal=CAN1_RX
PA12.Signal=CAN1_TX
PA2.GPIO_Label=RX_LED
PA2.Signal=GPIO_Output
PA3.GPIO_Label=FLASH1_CS
PA3.Signal=GPIO_Output
PA4.GPIO_Label=FLASH2_CS
PA4.Signal=GPIO_Output
PA5.GPIO_Label=FLASH3_CS
PA5.Signal=GPIO_Output
PA6.Signal=SPI1_MISO
PA7.Signal=SPI1_MOSI
PA8.GPIO_Label=CAN1_STB
PA8.Signal=GPIO_Output
PA9.Signal=I2C1_SCL
PB0.GPIO_Label=TMP_D_ALERT
PB0.Signal=GPXTI0
PB1.GPIO_Label=TMP_C_ALERT
PB1.Signal=GPXTI1
PB10.Signal=SPI2_SCK
PB11.Signal=I2C2_SDA
PB13.Signal=I2C2_SCL
PB14.Signal=SPI2_MISO
PB15.Signal=SPI2_MOSI
PB2.GPIO_Label=TMP_A_ALERT
PB2.Signal=GPXTI2
PB5.GPIO_Label=LR_NSS
PB5.Signal=GPIO_Output
PB6.GPIO_Label=LR_IO7
PB6.Signal=GPXTI6
PB7.GPIO_Label=LR_IO8
PB7.Signal=GPXTI7
PB8.GPIO_Label=LR_IO9
PB8.Signal=GPXTI8
PB9.GPIO_Label=LR_RST
PB9.Signal=GPXTI9
PC13.GPIO_Label=RF_INA_ALERT
PC13.Signal=GPXTI13

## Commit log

2026-05-03 🎀 Initial commit
    [TET.kicad_pcb, TET.kicad_sch]
2026-05-04 ✨ feat(schematic): start connections for STM32L4
    [TET-Power-Supply.kicad_sch, TET.kicad_pcb, TET.kicad_sch]
2026-05-04 ✨ feat(schematic): add pinout STM32
    [TET.kicad_sch]
2026-05-05 ♻️ ref(schematic): change MCU from 48 pins to 64 pins
    [TET.kicad_pcb, TET.kicad_sch]
2026-05-10 hardware(schematics): upload pre-review schematic
    [TET-Board-Control.kicad_sch, TET-MCU.kicad_sch, TET-Power-Supply.kicad_sch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]
2026-05-11 hardware(schematics): remove 3.3 V power injector #2
    [TET-Board-Control.kicad_sch, TET-MCU.kicad_sch, TET-Power-Supply.kicad_sch]
2026-05-11 hardware(schematic): link datasheet to all main components #1
    [TET-Power-Supply.kicad_sch, TET-RF-Transceiver.kicad_sch, TET.kicad_pcb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]
2026-05-11 hardware(schematic): fix Electrical Rules Check (ERC)
    [TET-Power-Supply.kicad_sch, TET-RF-Transceiver.kicad_sch, TET.kicad_pcb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]
2026-05-11 hardware(schematic): update documentation for all sheets
    [TET-Power-Supply.kicad_sch, TET-RF-Transceiver.kicad_sch, TET.kicad_pcb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]
2026-05-15 hardware(pcb_design): start PCB design
    [TET-Power-Supply.kicad_sch, TET-RF-Transceiver.kicad_sch, TET.kicad_pcb]
2026-05-16 hardware(schematic): add bulk capacitor on STM32L4 #5
    [TET-Power-Supply.kicad_sch, TET-RF-Transceiver.kicad_sch, TET.kicad_pcb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]
2026-05-18 feat(schematic): fix double pull-up resistor for LR_BUSY
    [TET-RF-Transceiver.kicad_sch, TET.kicad_pcb, TET.kicad_sch]
2026-05-18 hardware(pcb_design): components Micro-Placement
    [TET-Power-Supply.kicad_sch, TET-RF-Transceiver.kicad_sch, TET.kicad_pcb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]
2026-05-30 hardware(pcb_design): MCU components placement
    [TET.kicad_pcb]
2026-06-09 feat(hardware): implement TET module PCB design and restructure project
    [TET-Power-Supply.kicad_sch, TET-RF-Transceiver.kicad_sch, TET.kicad_pcb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]
2026-06-09 feat(hardware): complete PCB layout and project structure
    [BOM-TET.csv, TET-Power-Supply.kicad_sch, TET-RF-Transceiver.kicad_sch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]
2026-06-23 feat(hardware): release v1r2
    [BOM-TET.csv, TET-Power-Supply.kicad_sch, TET.kicad_pcb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]
